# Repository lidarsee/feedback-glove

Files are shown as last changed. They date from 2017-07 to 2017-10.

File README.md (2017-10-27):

# LIDARsee v2 Feedback Glove

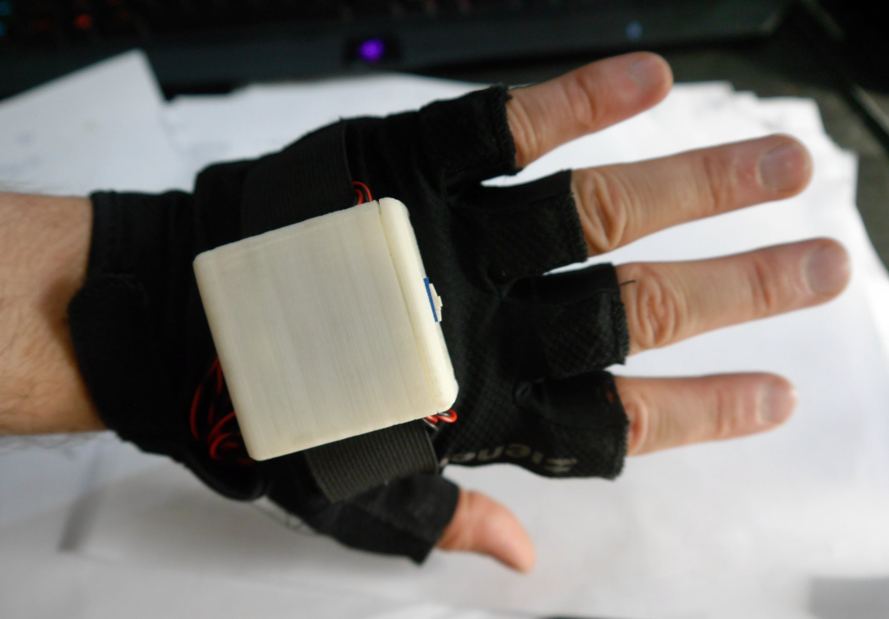
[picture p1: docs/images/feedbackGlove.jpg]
FeedbackGlove


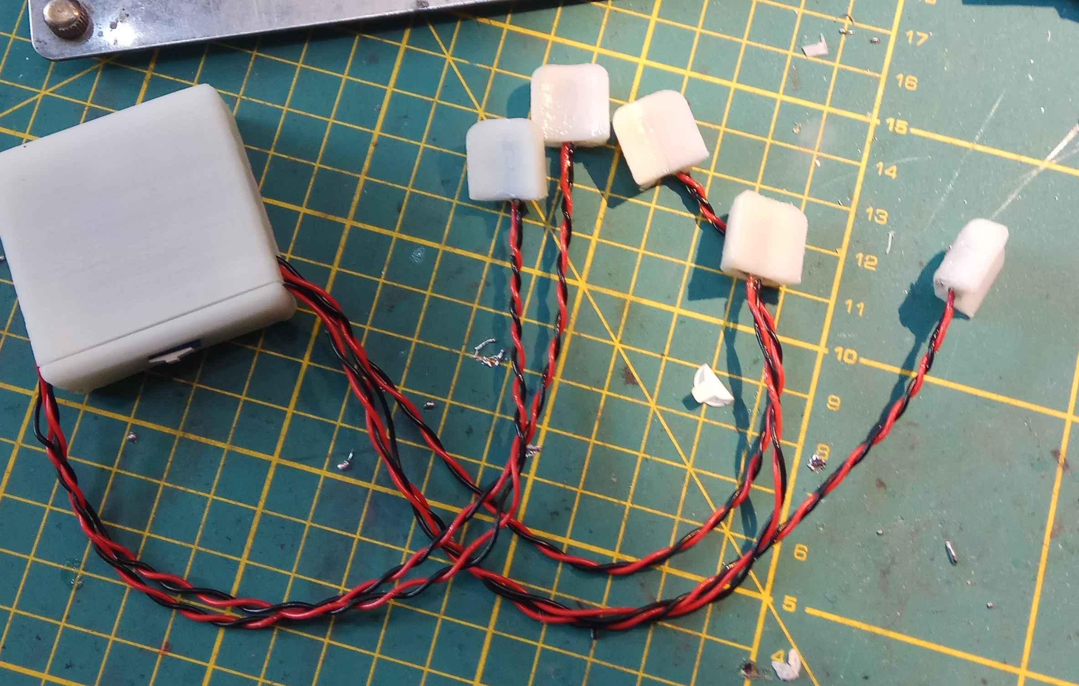
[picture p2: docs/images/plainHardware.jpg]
FeedbackGloveHardware


To control the glove you can simply send a UDP packet at the specified port. 

| The library uses a simple ASCII-protocoll to transfer data. 

| Name | : | Value |\r\n|

The UDP packet contains an ASCII string to set vibrationmotor2 to a PWM value of 0:
```
Vibramotor2:0<\r><\n>
```
... to Value 123:
```
Vibramotor2:123<\r><\n>
```
... and multiple values are also possible:
```
Vibramotor1:0<\r><\n>
Vibramotor2:123<\r><\n>
Vibramotor3:456<\r><\n>
Vibramotor4:10<\r><\n>
Vibramotor5:1023<\r><\n>
```

PWM range is from 0 to 1023.

Or use the GUI for testing:
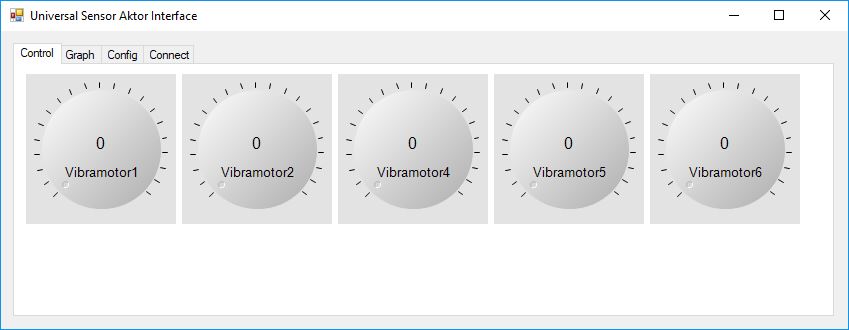
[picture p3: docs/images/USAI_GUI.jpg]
USAI_GUI

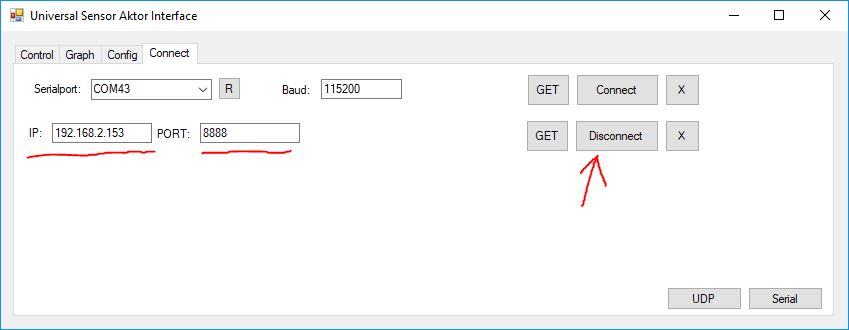
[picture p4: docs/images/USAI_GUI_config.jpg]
USAI_GUI_config


## To Do:
- The vibration motors consume a lot of power when starting. To remedy this problem, either the mounting of additional capacitors or limiting the maximum current by the software is recommended.
- Connect the motors to the battery directly

The library and the GUI is available under GPL 3.0 at:
- https://github.com/4ndreas/USAI
- https://github.com/4ndreas/USAI_GUI

## License

Hardware License: Creative Commons CC0 https://creativecommons.org/publicdomain/zero/1.0/legalcode

Software license: MIT License

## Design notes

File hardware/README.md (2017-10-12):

# LIDARsee v2 Feedback Glove
## Wiring

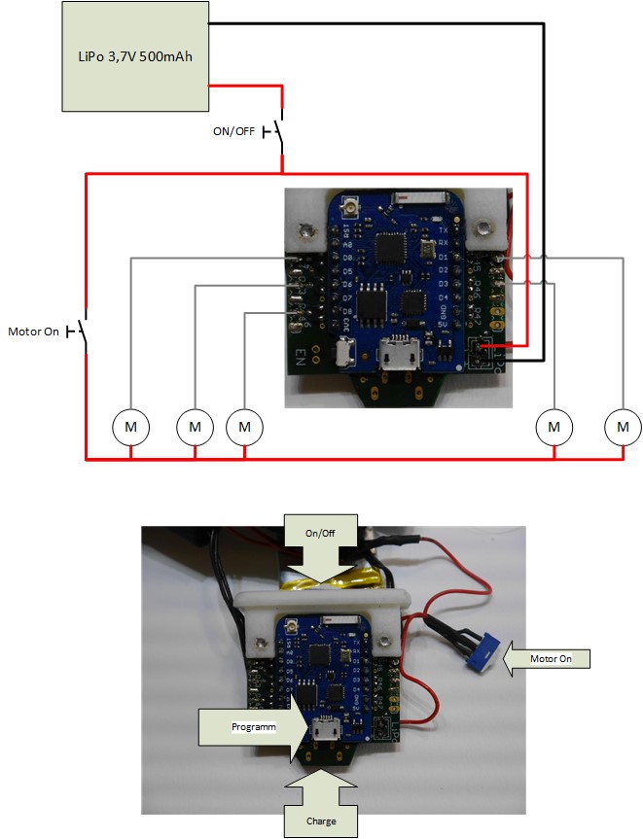
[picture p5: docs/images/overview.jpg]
overview


Right now we are powering the feedback motors directly from the battery. An additional switch is required to prevent that the motors are running during programming and charging.

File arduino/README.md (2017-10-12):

# LIDARsee Feedback Glove Arduino Sketch

Arduino Sketch for the hardware

- USAI_Glove_demo connects to a WiFi and uses a Soft AP as fallback
- USAI_UDP_Glove uses a Soft AP
- USAI_UDP_WiFi connects to a WiFi 

Set the Arduino IDE to:

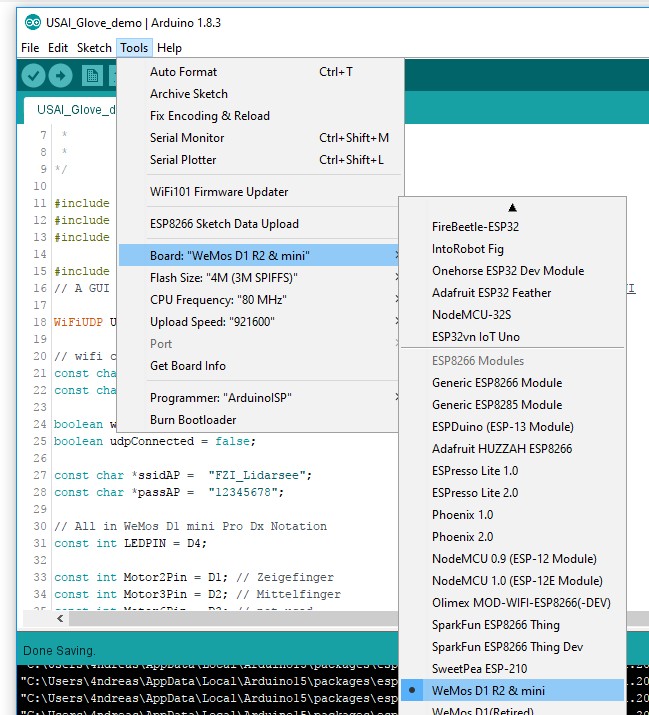
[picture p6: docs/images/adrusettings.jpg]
adrusettings


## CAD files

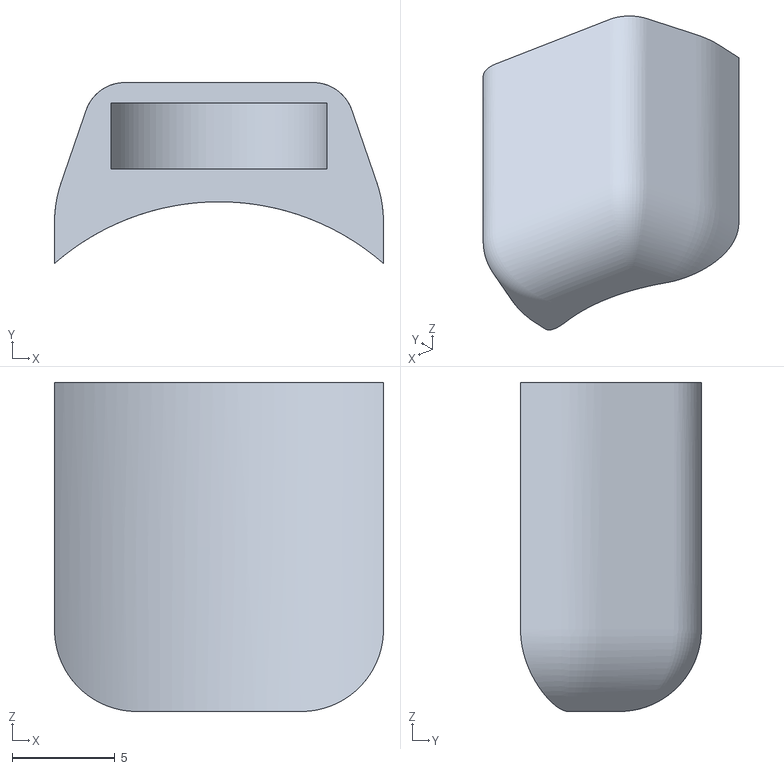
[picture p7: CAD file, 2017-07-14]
hardware/InventorCAD/print/vibramount_v2_0.stl
16.0 x 8.80 x 16.0

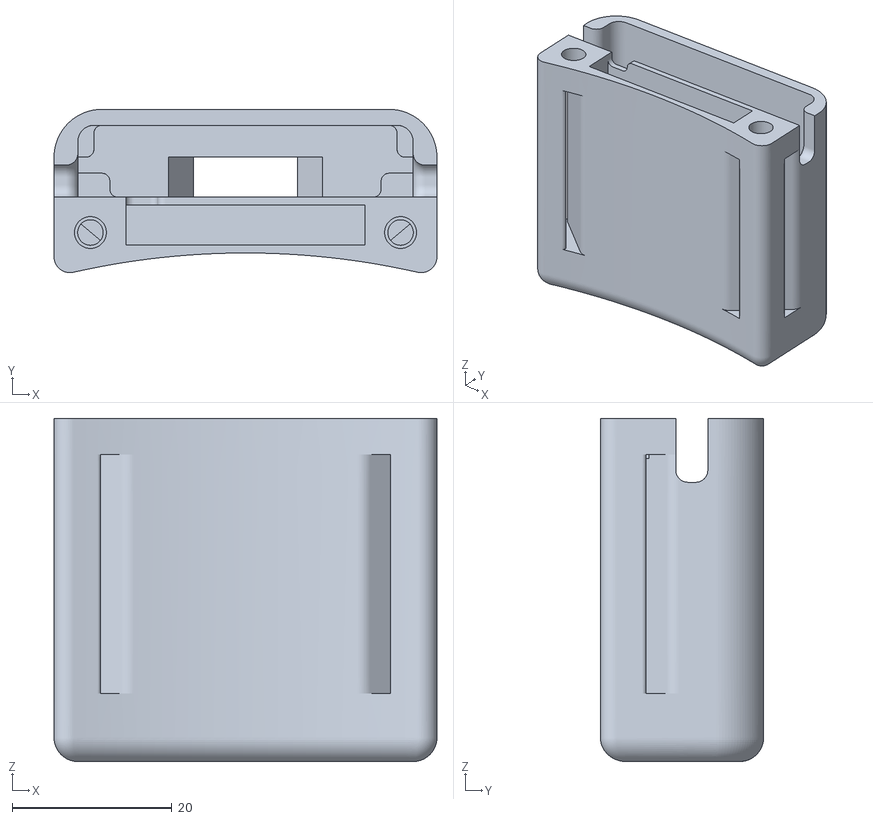
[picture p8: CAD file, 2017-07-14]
hardware/InventorCAD/print/feedbackGloveCase_part_A.stl
48.0 x 20.5 x 43.0

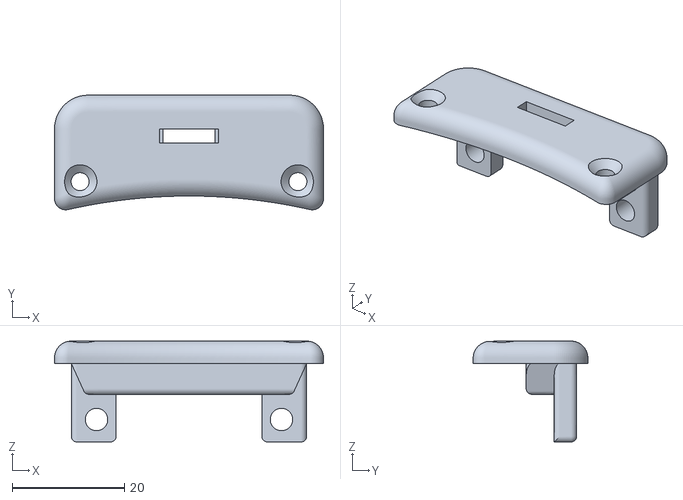
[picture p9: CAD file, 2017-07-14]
hardware/InventorCAD/print/feedbackGloveCase_part_B.stl
48.0 x 20.5 x 18.0

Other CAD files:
hardware/InventorCAD/feedbackGloveCase.ipt
hardware/InventorCAD/vibramount_v2.ipt

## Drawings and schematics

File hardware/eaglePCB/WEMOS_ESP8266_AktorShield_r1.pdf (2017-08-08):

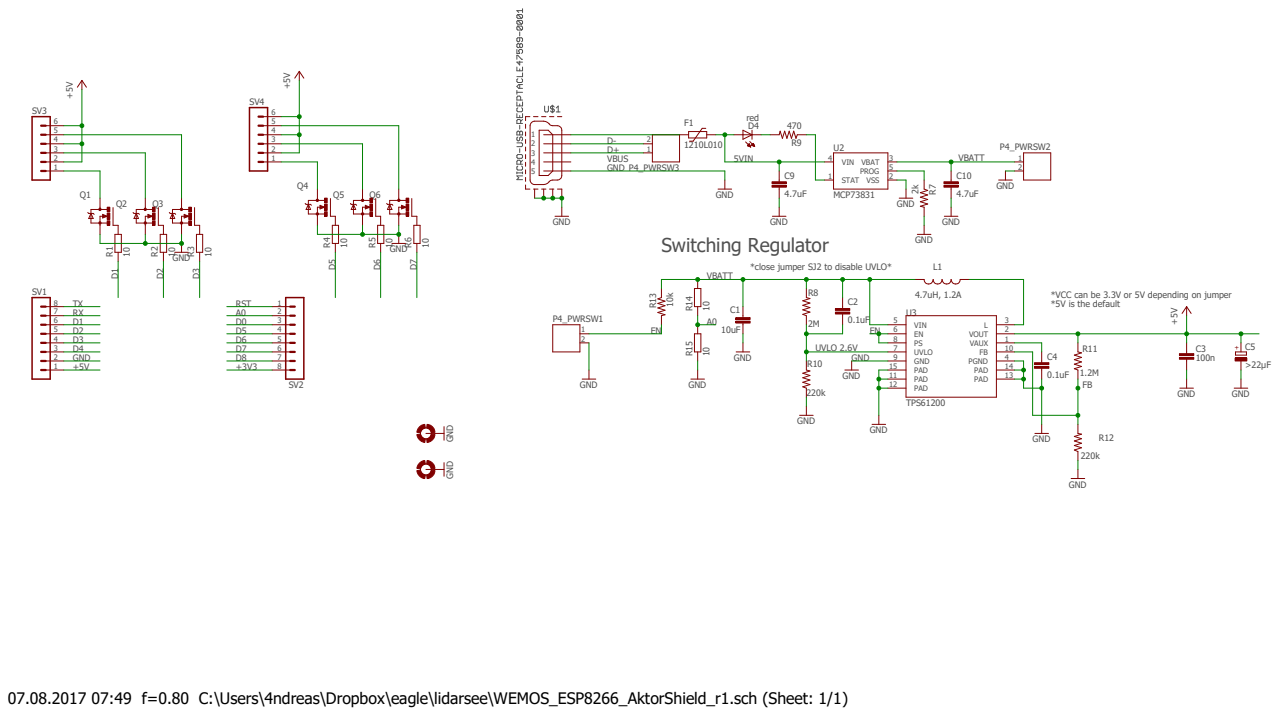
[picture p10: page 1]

*close jumper SJ2 to disable UVLO*

*VCC can be 3.3V or 5V depending on jumper

07.08.2017 07:49 f=0.80 C:\Users\4ndreas\Dropbox\eagle\lidarsee\WEMOS_ESP8266_AktorShield_r1.sch (Sheet: 1/1)

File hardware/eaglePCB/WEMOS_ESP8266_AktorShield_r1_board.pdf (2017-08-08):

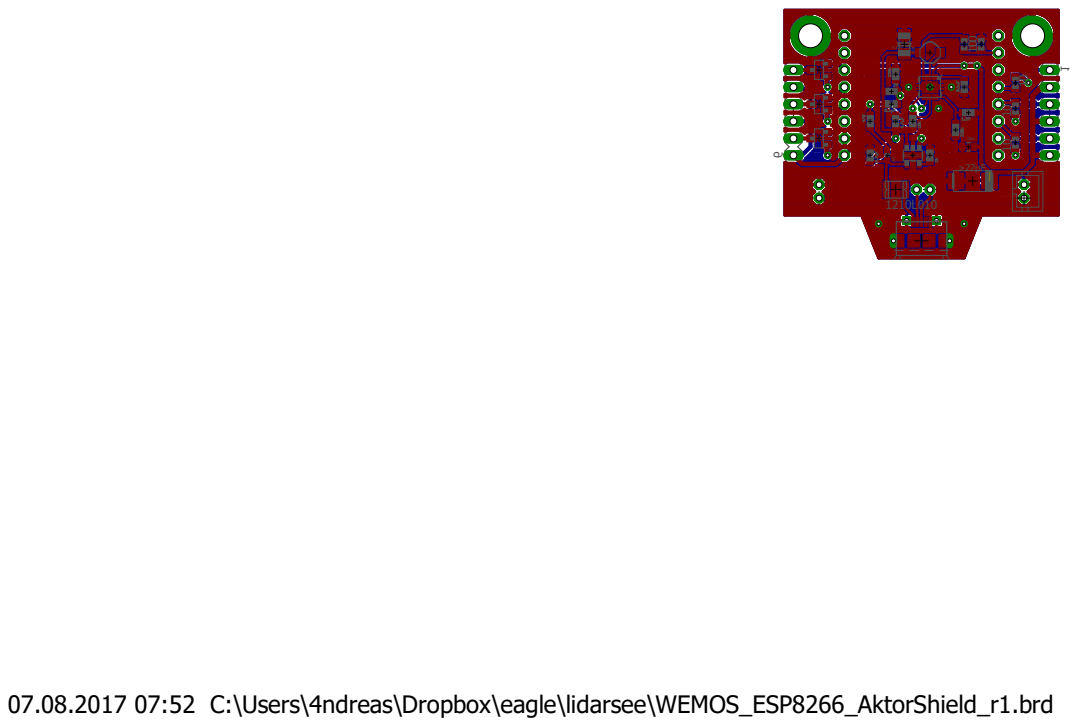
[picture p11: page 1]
6 10 10 10 redMCP73831; 100n ¹⁰uF4.7uH, 1.2A

07.08.2017 07:52 C:\Users\4ndreas\Dropbox\eagle\lidarsee\WEMOS_ESP8266_AktorShield_r1.brd ¹⁰ ¹⁰ ¹⁰

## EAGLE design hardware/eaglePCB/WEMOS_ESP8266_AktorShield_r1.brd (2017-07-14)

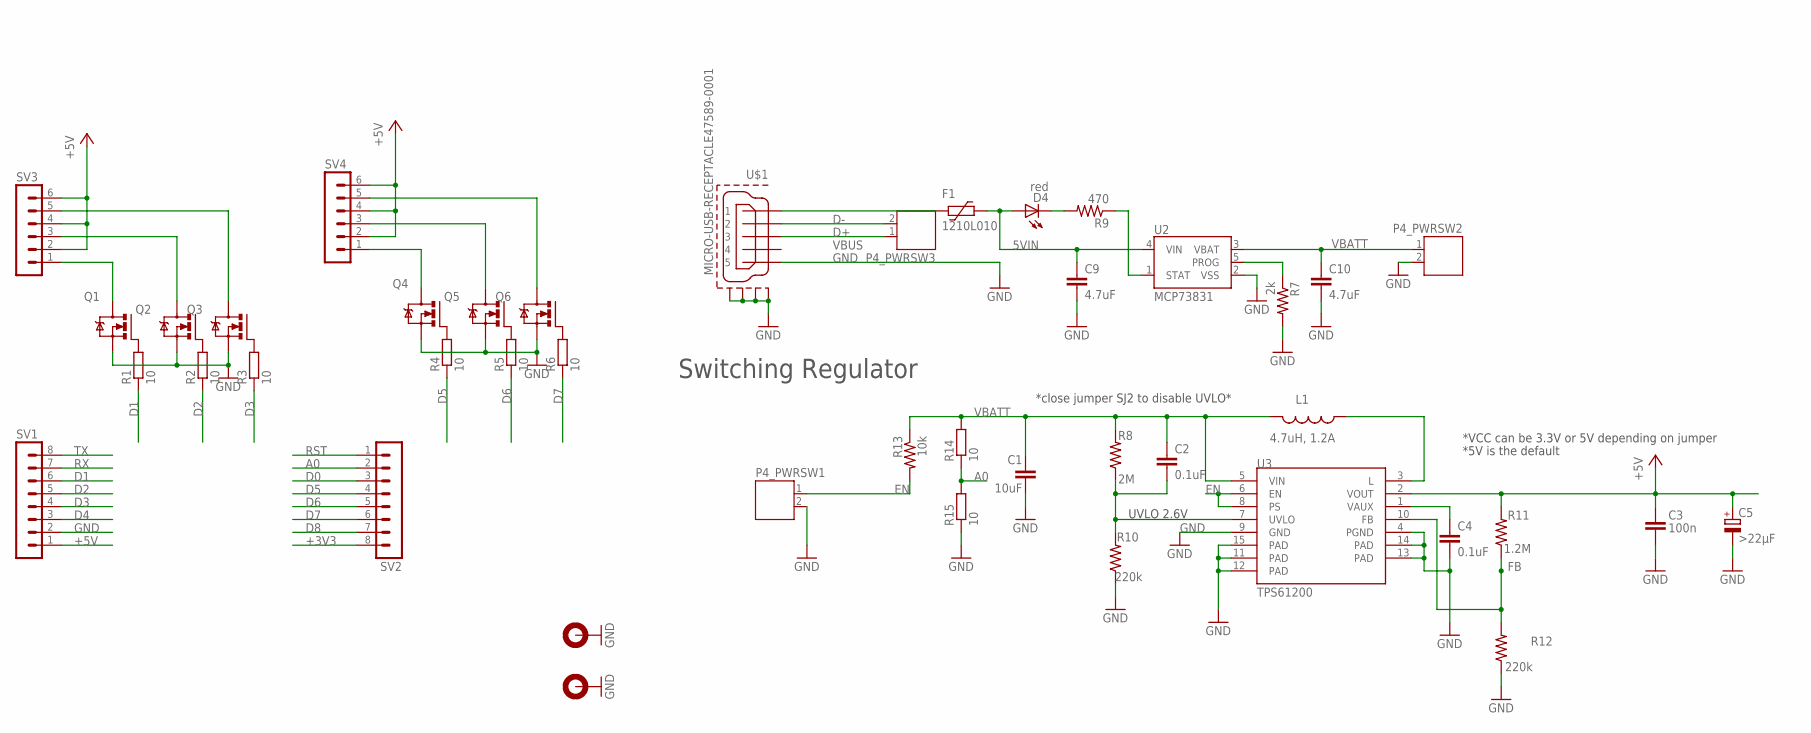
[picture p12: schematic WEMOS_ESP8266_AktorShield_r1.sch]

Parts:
C1: 10uF; 1206; MPN C1206C106K8RACTU
C2, C4: 0.1uF; 0603-CAP; MPN CC0603MRY5V9BB104
C3: 100n; 0805; MPN CC0603MRY5V9BB104
C5: >22µF; SMC_C
C9, C10: 4.7uF; 0603-CAP; MPN C0603C475K8PACTU
D4: red; LED-0603; MPN LSQ976-Z
F1: 1210L010; 1210L; MPN 1210L010WR
H7, H8: MOUNT-PAD-ROUND3.6; 3,6-PAD
L1: 4.7uH, 1.2A; CDRH2D09; MPN LQH3NPN4R7MJ0L
P4_PWRSW1, P4_PWRSW2, P4_PWRSW3: JST-PH2; MPN B2B-PH-K-S(LF)(SN)
Q1, Q2, Q3, Q4, Q5, Q6: IRLML6344; SOT23; MPN IRLML6344TRPBF
R1, R2, R3, R4, R5, R6, R14, R15: 10; R0603; MPN CRCW060310R0FKEA
R7: 2k; 0603-RES; MPN RC0603FR-072K2L.
R8: 2M; 0603-RES; MPN RK73H1JTTD1204F
R9: 470; 0603-RES; MPN MCHP03W8F4700T5E
R10, R12: 220k; 0603-RES; MPN MCHP03W8F2203T5E
R11: 1.2M; 0603-RES; MPN MCMR06W2004FTL
R13: 10k; 0603-RES; MPN MCMR06X1002FTL
SV1, SV2: MA08-1SMALL; MA08-1S
SV3, SV4: MA06-1
U2: MCP73831; SOT23-5; MPN MCP73831T-2ACI/OT
U3: TPS61200; QFN-10_PAD; MPN TPS61200DRCT
U$1: MICRO-USB-RECEPTACLE47589-0001; 47589-0001; MPN 47589-0001

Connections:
5VIN: C9.1, D4.A, F1.1, U2.4 (VIN)
+3V3: SV2.8
+5V: C3.1, C5.+, R11.2, SV1.1, SV3.2, SV3.4, SV3.6, SV4.2, SV4.4, SV4.6, U3.2 (VOUT)
A0: R14.1, R15.2, SV2.2
D0: SV2.3
D1: R1.1, SV1.6
D2: R2.1, SV1.5
D3: R3.1, SV1.4
D4: SV1.3
D5: R4.1, SV2.4
D6: R5.1, SV2.5
D7: R6.1, SV2.6
D8: SV2.7
D+: P4_PWRSW3.1, U$1.3
D-: P4_PWRSW3.2, U$1.2
EN: P4_PWRSW1.1, R13.2, U3.6 (EN), U3.8 (PS)
FB: R11.1, R12.2, U3.10 (FB)
GND: C1.2, C3.2, C4.2, C5.-, C9.2, C10.2, H7.B3,6, H8.B3,6, P4_PWRSW1.2, P4_PWRSW2.2, Q1.2 (S), Q2.2 (S), Q3.2 (S), Q4.2 (S), Q5.2 (S), Q6.2 (S), R7.2, R10.1, R12.1, R15.1, SV1.2, U2.2 (VSS), U3.4 (PGND), U3.9 (GND), U3.11 (PAD), U3.12 (PAD), U3.13 (PAD), U3.14 (PAD), U3.15 (PAD), U$1.5, U$1.CASING1 (GND1), U$1.CASING2 (GND2), U$1.CASING3 (GND3), U$1.CASING4 (GND4)
unnamed: Q1.1 (G), R1.2
unnamed: Q2.1 (G), R2.2
unnamed: Q3.1 (G), R3.2
unnamed: Q3.3 (D), SV3.5
unnamed: Q1.3 (D), SV3.1
unnamed: Q2.3 (D), SV3.3
unnamed: Q4.1 (G), R4.2
unnamed: Q5.1 (G), R5.2
unnamed: Q6.1 (G), R6.2
unnamed: Q4.3 (D), SV4.1
unnamed: Q5.3 (D), SV4.3
unnamed: Q6.3 (D), SV4.5
unnamed: R7.1, U2.5 (PROG)
unnamed: R9.1, U2.1 (STAT)
unnamed: D4.C, R9.2
unnamed: L1.P$1 (1), U3.3 (L)
unnamed: C4.1, U3.1 (VAUX)
RST: SV2.1
RX: SV1.7
TX: SV1.8
UVLO: C2.2, R8.1, R10.2, U3.7 (UVLO)
VBATT: C1.1, C2.1, C10.1, L1.P$2 (2), P4_PWRSW2.1, R8.2, R13.1, R14.2, U2.3 (VBAT), U3.5 (VIN)
VBUS: F1.2, U$1.1

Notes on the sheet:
UVLO 2.6V
*close jumper SJ2 to disable UVLO*
Switching Regulator
*VCC can be 3.3V or 5V depending on jumper
*5V is the default

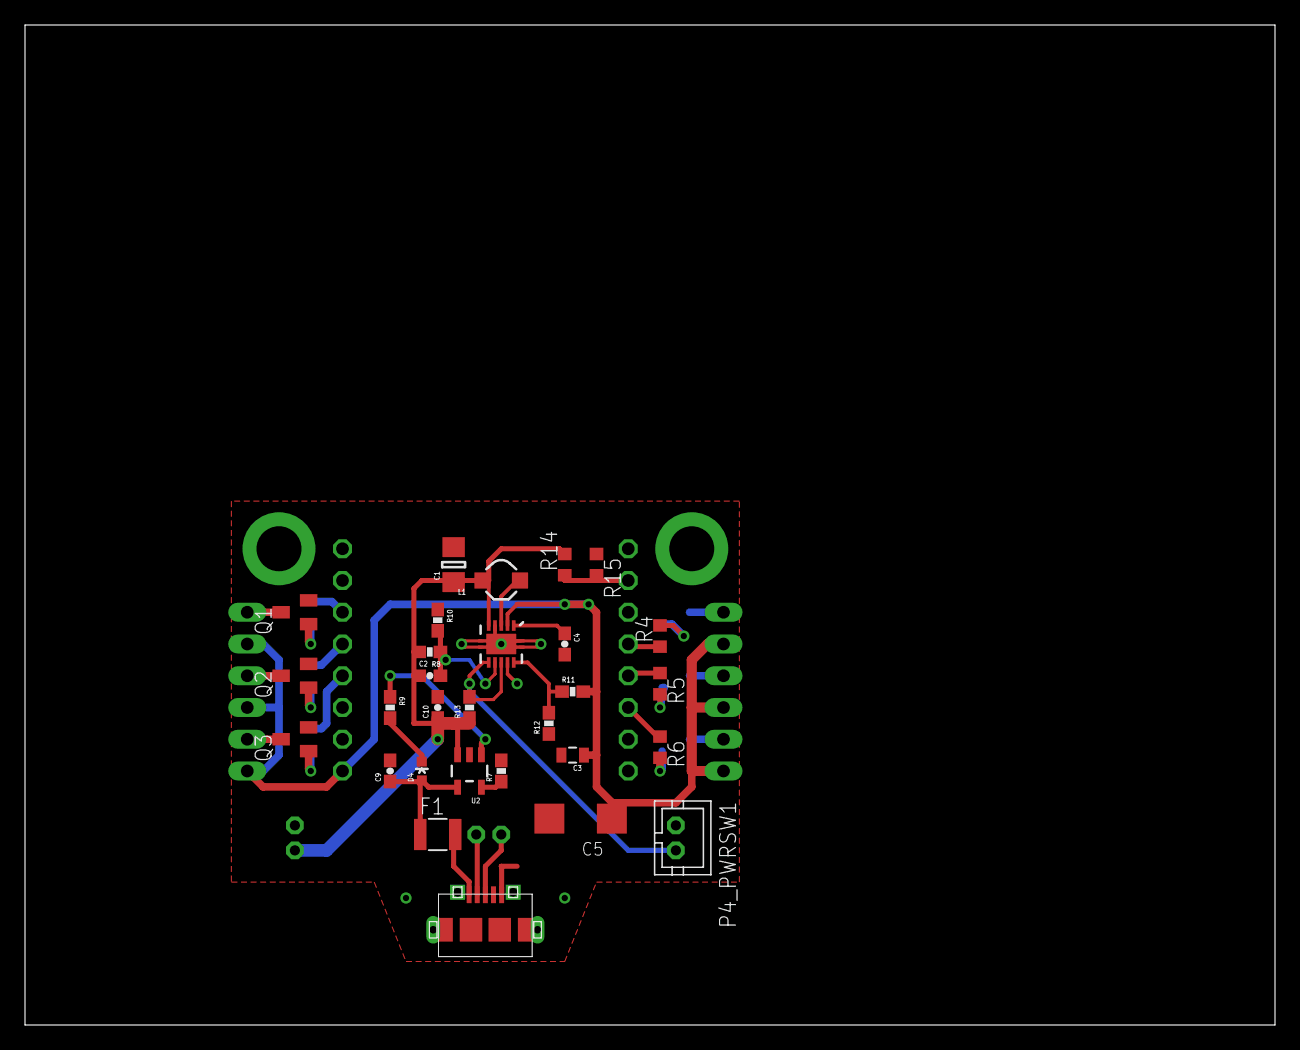
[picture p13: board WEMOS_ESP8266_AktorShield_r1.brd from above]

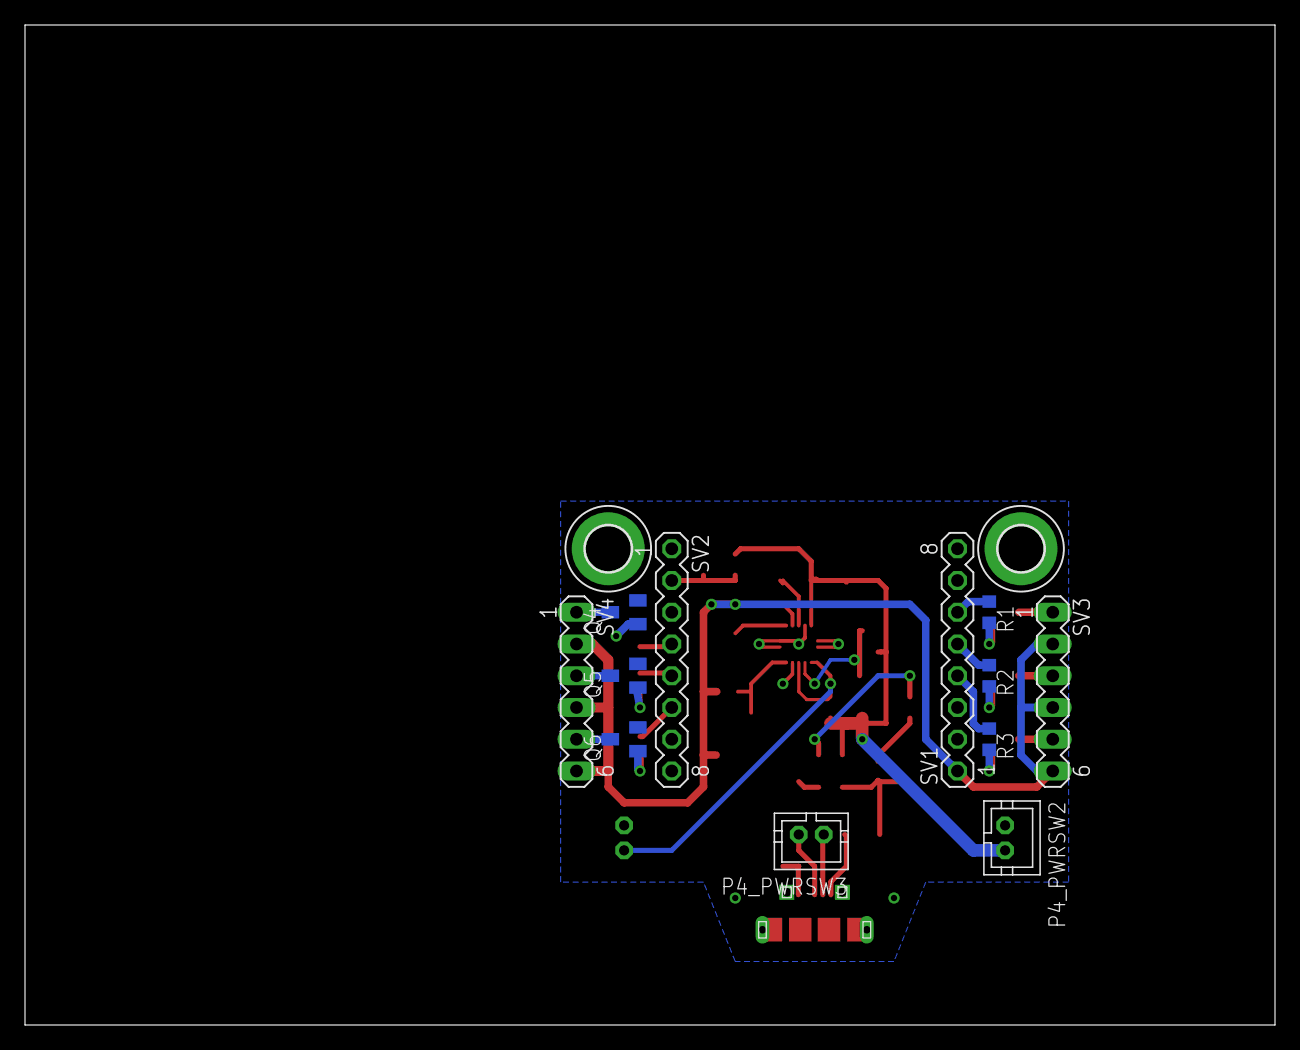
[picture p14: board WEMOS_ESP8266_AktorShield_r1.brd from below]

Board: 2 copper layers, 100.0 x 80.0 mm, 43 parts (14 on the bottom side), 34 nets.

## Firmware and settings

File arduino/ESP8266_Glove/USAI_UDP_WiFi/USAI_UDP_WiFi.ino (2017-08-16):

/* This is an example of the Universal Sensor Actor Library
 * It's designed for a WeMos d1 mini pro Module. 
 * Select "WeMos D1 R2 & Mini" as board in the tools menue
 * 
 * This example connects to a local acces point and waits for data.
 * You can connect to the board with the USAI GUI from
 * 
 * 
*/

#include <ESP8266WiFi.h>
#include <WiFiClient.h>
#include <WiFiUDP.h>

#include "usai.h"   // download from https://github.com/4ndreas/USAI
// A GUI for interacting can be downloaded from https://github.com/4ndreas/USAI_GUI

WiFiUDP Udp;

// wifi connection variables
const char *ssid =	"YourSSIDHere";
const char *pass =	"YourPSKHere";

boolean wifiConnected = false;
boolean udpConnected = false;

// All in WeMos D1 mini Pro Dx Notation
// LED D4

// Motor1 D1
// Motor1 D2
// Motor1 D3
// Motor1 D5
// Motor1 D6
// Motor1 D7


const int LEDPIN = D4;
const int Motor1Pin = D1;
const int Motor2Pin = D2;
const int Motor3Pin = D3;

const int Motor4Pin = D5;
const int Motor5Pin = D6;
const int Motor6Pin = D7;

int Vibramotor1 = 0;
int Vibramotor2 = 0;
int Vibramotor3 = 0;
int Vibramotor4 = 0;
int Vibramotor5 = 0;
int Vibramotor6 = 0;

int BatteryVoltage = 0;

int TestValue = 0;

//start the library, pass in the data details and the name of the serial port. Can be Serial, Serial1, Serial2, etc.
//for network use &Udp
usai Sensors(&Udp);
unsigned int localPort = 8888;      // local port to listen on


uValue V1("Vibramotor1",Control,&Vibramotor1);
uValue V2("Vibramotor2",Control,&Vibramotor2);
uValue V3("Vibramotor3",Control,&Vibramotor3);
uValue V4("Vibramotor4",Control,&Vibramotor4);
uValue V5("Vibramotor5",Control,&Vibramotor5);
uValue V6("Vibramotor6",Control,&Vibramotor6);

uValue V7("BatteryVoltage",Config,&BatteryVoltage);

void setup(){

  pinMode(A0, INPUT);
  pinMode(Motor1Pin, OUTPUT);
  pinMode(Motor2Pin, OUTPUT);
  pinMode(Motor3Pin, OUTPUT);
  pinMode(Motor4Pin, OUTPUT);
  pinMode(Motor5Pin, OUTPUT);
  pinMode(Motor6Pin, OUTPUT);

  digitalWrite(Motor1Pin, LOW);
  digitalWrite(Motor2Pin, LOW);
  digitalWrite(Motor3Pin, LOW);
  digitalWrite(Motor4Pin, LOW);
  digitalWrite(Motor5Pin, LOW);
  digitalWrite(Motor6Pin, LOW);

	Serial.begin(115200);
	Serial.println("");
	Serial.println("");
	Serial.println("StartWifi");

  // Initialise wifi connection
	WiFi.begin(ssid, pass);

	while (WiFi.status() != WL_CONNECTED) {
		delay(500);
		Serial.print(".");
	}
  Serial.println ("");
  Serial.println ("Wifi Connected");
  
  IPAddress myIP = WiFi.localIP();
  Udp.begin(localPort);

	
	
  Serial.print("local IP is: ");  
  Serial.println(myIP);
  Serial.print("UDP USAI port is: ");
  Serial.println(localPort);
  Serial.println("");
  delay(100);

	Sensors.begin();
	Sensors.addValue(&V1);
	Sensors.addValue(&V2);
	//Sensors.addValue(&V3);  // not used
	Sensors.addValue(&V4);
  Sensors.addValue(&V5);
  Sensors.addValue(&V6);
  Sensors.addValue(&V7);  // Battery Voltage
  
  Sensors.sendConfig();
}

void loop(){
	
BatteryVoltage = analogRead(A0);
Sensors.processSensorData();

analogWrite(Motor1Pin, Vibramotor1);
analogWrite(Motor2Pin, Vibramotor2);
//analogWrite(Motor3Pin, Vibramotor3);
analogWrite(Motor4Pin, Vibramotor4);
analogWrite(Motor5Pin, Vibramotor5);
analogWrite(Motor6Pin, Vibramotor6);

delay(10);
}

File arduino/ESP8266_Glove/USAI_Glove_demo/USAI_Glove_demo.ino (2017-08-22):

/* This is an example of the Universal Sensor Actor Library
 * It's designed for a WeMos d1 mini pro Module. 
 * Select "WeMos D1 R2 & Mini" as board in the tools menue
 * 
 * This example connects to a local acces point and waits for data.
 * You can connect to the board with the USAI GUI from
 * 
 * 
*/

#include <ESP8266WiFi.h>
#include <WiFiClient.h>
#include <WiFiUDP.h>

#include "usai.h"   // download from https://github.com/4ndreas/USAI
// A GUI for interacting can be downloaded from https://github.com/4ndreas/USAI_GUI

WiFiUDP Udp;

// wifi connection variables
const char *ssid =	"YourSSIDHere";
const char *pass =	"YourPSKHere";

boolean wifiConnected = false;
boolean udpConnected = false;

const char *ssidAP =  "FZI_Lidarsee";
const char *passAP =  "12345678";

// All in WeMos D1 mini Pro Dx Notation
const int LEDPIN = D4;

const int Motor2Pin = D1; // Zeigefinger
const int Motor3Pin = D2; // Mittelfinger
const int Motor6Pin = D3; // not used
const int Motor4Pin = D6; // Ringfinger
const int Motor5Pin = D5; // Kleinerfinger
const int Motor1Pin = D7; // Daumen

int Vibramotor1 = 0;
int Vibramotor2 = 0;
int Vibramotor3 = 0;
int Vibramotor4 = 0;
int Vibramotor5 = 0;
int Vibramotor6 = 0;

int BatteryDigit = 0;
const float BatteryBittoV = 0.00679; //  V/bit
float BatteryVoltage = 0;

int MasterValue = 500;

boolean Finger1 = false;
boolean Finger2 = false;
boolean Finger3 = false;
boolean Finger4 = false;
boolean Finger5 = false;

//start the library, pass in the data details and the name of the serial port. Can be Serial, Serial1, Serial2, etc.
//for network use &Udp
usai Sensors(&Udp);
unsigned int localPort = 8888;      // local port to listen on


uValue V1("Vibramotor1",Control,&Vibramotor1);
uValue V2("Vibramotor2",Control,&Vibramotor2);
uValue V3("Vibramotor3",Control,&Vibramotor3);
uValue V4("Vibramotor4",Control,&Vibramotor4);
uValue V5("Vibramotor5",Control,&Vibramotor5);
//uValue V6("Vibramotor6",Control,&Vibramotor6);

uValue V7("BatteryVoltageBit",Config,&BatteryDigit);
uValue V8("BatteryVoltage",Config,&BatteryVoltage);

uValue V11("Master",Control,&MasterValue);

uValue V12("Daumen",Control,&Finger1);
uValue V13("Zeigefinger",Control,&Finger2);
uValue V14("Mittelfinger",Control,&Finger3);
uValue V15("Ringfinger",Control,&Finger4);
uValue V16("Kleinerfinger",Control,&Finger5);

void setup(){

  pinMode(A0, INPUT);
  pinMode(LEDPIN, OUTPUT);
  pinMode(Motor1Pin, OUTPUT);
  pinMode(Motor2Pin, OUTPUT);
  pinMode(Motor3Pin, OUTPUT);
  pinMode(Motor4Pin, OUTPUT);
  pinMode(Motor5Pin, OUTPUT);
  pinMode(Motor6Pin, OUTPUT);

  digitalWrite(Motor1Pin, LOW);
  digitalWrite(Motor2Pin, LOW);
  digitalWrite(Motor3Pin, LOW);
  digitalWrite(Motor4Pin, LOW);
  digitalWrite(Motor5Pin, LOW);
  digitalWrite(Motor6Pin, LOW);

	Serial.begin(115200);
	Serial.println("");
	Serial.println("");
	Serial.println("StartWifi");

  Serial.println("Try to connect to:");
  Serial.print("SSID:");Serial.println(ssid);
  Serial.print("Pass:");Serial.println(pass);
  Serial.println("Try for 30 secondes than open soft AP");

  int timeoutCounter = 0;
  // Initialise wifi connection
	WiFi.begin(ssid, pass);
	while (WiFi.status() != WL_CONNECTED) {
		delay(500);
		Serial.print(".");
    wifiConnected = true;
    timeoutCounter++;
    if(timeoutCounter > 60)
    {
      wifiConnected = false;
      break;
    }
    
	}
  
  Serial.println ("");
  IPAddress myIP;
  if(wifiConnected)
  {
    Serial.println ("Wifi Connected");
    myIP = WiFi.localIP();
    Serial.print("local IP is: "); 
  }
  else  // open soft AP 
  {
    WiFi.mode(WIFI_AP);
    Serial.println("No WiFi found open SoftAP");
    Serial.print("SSID:");Serial.println(ssidAP);
    Serial.print("Pass:");Serial.println(passAP);
    WiFi.softAP(ssidAP, passAP);
    Serial.print("AP IP address: ");
    myIP = WiFi.softAPIP();    
  }
  
  Udp.begin(localPort);
	
  Serial.println(myIP);
  Serial.print("UDP USAI port is: ");
  Serial.println(localPort);
  Serial.println("");
  delay(100);

	Sensors.begin();
	Sensors.addValue(&V1);
	Sensors.addValue(&V2);
	Sensors.addValue(&V3);
	Sensors.addValue(&V4);
  Sensors.addValue(&V5);
  //Sensors.addValue(&V6); // not used
  Sensors.addValue(&V7);  // Battery Voltage in Bit
  Sensors.addValue(&V8);  // Battery Voltage in V

  Sensors.addValue(&V11); // master control 
  Sensors.addValue(&V12);
  Sensors.addValue(&V13);
  Sensors.addValue(&V14);
  Sensors.addValue(&V15);
  Sensors.addValue(&V16);
  
  Sensors.sendConfig();
}


bool ledtoggle = false;
int ledcounter = 0;
int ledBlinkDelay = 100;
void loop(){
	
// get Battery Voltage
BatteryDigit = analogRead(A0);
BatteryVoltage =  BatteryDigit * BatteryBittoV;

// to do shutdown if Battery is to low

Sensors.processSensorData();

if(BatteryVoltage < 3.2)
{
  // shutdown
  Vibramotor1 = 0;
  Vibramotor2 = 0;
  Vibramotor3 = 0;
  Vibramotor4 = 0;
  Vibramotor5 = 0;
  Vibramotor6 = 0;
  MasterValue = 0;

  ledBlinkDelay = 30;
}

SetMotors();



delay(10);

ledcounter++;
if(ledcounter > ledBlinkDelay)
{
  ledcounter = 0;
  if(ledtoggle)
  {
    digitalWrite(LEDPIN, HIGH);
    ledtoggle = false;
  }
  else
  {
    digitalWrite(LEDPIN, LOW);
    ledtoggle = true;
  }
}

} // end Loop

void SetMotors()
{
if(Finger1)
{
  if( Vibramotor1 >0)
  {
    analogWrite(Motor1Pin, Vibramotor1);    
  }
  else
  {
    analogWrite(Motor1Pin, MasterValue);
  }
}
else
{
  analogWrite(Motor1Pin, 0);
}

if(Finger2)
{
  if( Vibramotor2 >0)
  {
    analogWrite(Motor2Pin, Vibramotor2);    
  }
  else
  {
    analogWrite(Motor2Pin, MasterValue);
  }
}
else
{
  analogWrite(Motor2Pin, 0);
}

if(Finger3)
{
  if( Vibramotor3 >0)
  {
    analogWrite(Motor3Pin, Vibramotor3);    
  }
  else
  {
    analogWrite(Motor3Pin, MasterValue);
  }
}
else
{
  analogWrite(Motor3Pin, 0);
}

if(Finger4)
{
  if( Vibramotor4 >0)
  {
    analogWrite(Motor4Pin, Vibramotor4);    
  }
  else
  {
    analogWrite(Motor4Pin, MasterValue);
  }
}
else
{
  analogWrite(Motor4Pin, 0);
}

if(Finger5)
{
  if( Vibramotor5 >0)
  {
    analogWrite(Motor5Pin, Vibramotor5);    
  }
  else
  {
    analogWrite(Motor5Pin, MasterValue);
  }
}
else
{
  analogWrite(Motor5Pin, 0);
}  
}

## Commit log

2017-08-08 pcb pdf
2017-08-08 License and folder change
    [WEMOS_ESP8266_AktorShield_r1.brd, WEMOS_ESP8266_AktorShield_r1.sch, feedbackGloveCase.ipt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]
2017-08-16 Arduino Code update
2017-08-22 New Arduino Scetch with more functions
2017-08-31 wireing overview

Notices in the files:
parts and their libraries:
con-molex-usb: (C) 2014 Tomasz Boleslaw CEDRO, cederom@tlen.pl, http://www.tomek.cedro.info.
